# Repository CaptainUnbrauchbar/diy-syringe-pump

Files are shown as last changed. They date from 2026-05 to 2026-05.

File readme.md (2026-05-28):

# DIY Syringe Pump project

This is the code for a DIY syringe pump project. The project targets an Arduino UNO R4 Minima and uses a stepper motor to control the infusion rate of a syringe. The code includes settings for the motor, syringe, and user interface, as well as functions for controlling the motor and displaying information on an LCD screen.

The CAD Files are designed for use with a '50ml BBRAUN Perfusor Syringe' but can easily be adjusted for any other syringe.

Arduino UNO R4 Minima note: the sketch uses `Serial1` on D0/D1 for the TMC2209 UART. For the Adafruit TMC2209 breakout with one `UART` pin, connect that single UART signal to both D1/TX1 and D0/RX1 so the sketch can send commands and read driver status. The backward endstop input moves to D11 on UNO R4.

See [hardware-connection-overview.html](hardware-connection-overview.html) for the full pin assignment and wiring overview.

Parts list incomplete, following soon

Parts list:

| Item | Qty | Description | Link | Notes |
| --- | ---: | --- | --- | --- |
| Arduino UNO R4 Minima | 1 |  |  |  |
| NEMA 17 Stepper motor | 1 |  |  |  |
| TMC2209 Stepper driver | 1 |  |  |  |
| T8 Spindle | 1 | |  |  |
| M8 Linear Rod | 2 |  |  | 
| Coupling Motor <-> T8 Spindle | 1 | | |
| LCD display 16x2, Arduino Uno Header | 1 |  |  |  |
| Power supply (12V, 2A recommended) | 1 |  |  |  |
| Endstop Switch | 2 |  |  |  |
| Buzzer | 1 |  |  |  |

| Bearings | Qty | Description |
| --- | ---: | --- |
| LM8SUU | 2 | Linear bearing 8mm x 15mm x 17mm |
| T8 Flange Bearing | 1 | Flange bearing for T8 spindle |

| Screws | Qty |
| --- | ---: |
| M2 Flathead | 6 |
| M3 Countersunk Head | 16+ |
| M3 Flathead | 4 |
| M5 Flathead | 2 |

CAD Files created with FreeCAD, 3D Printed with PLA

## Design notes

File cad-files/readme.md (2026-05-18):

# Perfusor CAD Files - Created with FreeCAD

Meshes exported in high quality

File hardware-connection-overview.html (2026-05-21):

# DIY Syringe Pump Hardware Connection Overview

This page matches the current diy-syringe-pump.ino sketch for Arduino UNO R4 Minima. It assumes the 2.4/2.8 inch Uno-style parallel TFT shield is installed, and that the motor is driven through an Adafruit TMC2209 breakout with a single half-duplex UART pin.

Target board: UNO R4 Minima Display: Uno parallel TFT shield Driver: Adafruit TMC2209 breakout Current sketch uses UART readback

## Quick Wiring Summary

### UNO R4 Pins In Use

D0TMC2209 UART net (RX1)

D1TMC2209 UART net (TX1)

D2TFT data bit D2

D3TFT data bit D3

D4TFT data bit D4

D5TFT data bit D5

D6TFT data bit D6

D7TFT data bit D7

D8TFT data bit D0, touch XP

D9TFT data bit D1, touch YM

D10TMC2209 STEP

D11Backward endstop

D13Buzzer positive

A0TFT RD

A1TFT WR

A2TFT CD/RS, touch XM

A3TFT CS, touch YP

A4TFT RESET

A5Forward endstop

5VTMC2209 VDD, TFT shield VCC

GNDCommon ground for everything

Direct logic signal Shared with TFT/touch shield Power or ground

### TMC2209 Breakout

- UNO R4 D10 -> TMC2209 STEP
- UNO R4 D1 / TX1 -> TMC2209 UART net
- UNO R4 D0 / RX1 -> same TMC2209 UART net
- UNO R4 5V -> TMC2209 VDD
- UNO R4 GND -> TMC2209 GND
- Motor PSU + -> TMC2209 terminal +
- Motor PSU - -> TMC2209 terminal - / GND
- Stepper coil A -> 1A / 1B
- Stepper coil B -> 2A / 2B

### Endstops and Buzzer

- Forward endstop -> A5
- Backward endstop -> D11
- Buzzer + -> D13
- Buzzer - -> GND

The TFT shield already occupies D2-D9 and A0-A4. Those pins are not free for other hardware.

Important TMC2209 UART note: this sketch does more than send commands; it also verifies readback from the driver. Because the Adafruit breakout has a single UART pin, that pin has to sit on a shared half-duplex UART net that reaches both D1/TX1 and D0/RX1. A one-way TX-only connection is not enough for this sketch.

## What The Sketch Actually Uses

### Used on the TMC2209

- STEP is used directly from D10.
- UART is used for configuration, enable/disable, and motor direction.
- VDD, GND, and motor power are required.
- 1A / 1B / 2A / 2B go to the motor coils.

### Not used by this sketch

- DIR is not wired because direction is sent over UART.
- EN is not wired because enable is sent over UART.
- DIAG and INDEX are not connected.
- MS1 / MS2 are not required because microstepping is configured over UART.

If UART is not working, the sketch will usually stop with a TMC2209 UART error instead of starting the pump.

## Pin Assignment Table

UNO R4 Pin | Connected To | Purpose | Notes
D0 / RX1 | TMC2209 UART | UART readback from driver | Must be on the same single-wire UART net as the breakout UART pin.
D1 / TX1 | TMC2209 UART | UART commands to driver | USB upload/monitor on UNO R4 is still separate from this pin pair.
D10 | TMC2209 STEP | Step pulse output | Still required even though other driver control is done over UART.
D11 | Backward endstop | Retract/home limit input | Moved here because D0 is used for Serial1 on UNO R4.
D13 | Buzzer positive | Alarm/status sound | Connect buzzer negative to GND.
A5 | Forward endstop | Infusion-end limit input | Separate from the TFT shield pins.
D2-D9 | TFT shield data bus | Parallel display interface | The shield expects these exact Uno-style pins.
A0-A4 | TFT shield control pins | RD/WR/CD/CS/RESET | These are also part of the touch-screen sharing arrangement.
D8, D9, A2, A3 | Resistive touch panel | Touch sensing | These are shared with the TFT shield and are already handled by the sketch.
5V | TMC2209 VDD, TFT shield VCC | Logic power | TMC2209 logic should match the UNO R4's 5 V logic supply.
GND | All grounds | Common reference | UNO, TMC2209, motor PSU, buzzer, and endstops must share ground.

## TFT Shield Map

Shield Signal | UNO R4 Pin | Notes
LCD_D0 | D8 | Shared with touch XP
LCD_D1 | D9 | Shared with touch YM
LCD_D2 | D2 | Shield bus
LCD_D3 | D3 | Shield bus
LCD_D4 | D4 | Shield bus
LCD_D5 | D5 | Shield bus
LCD_D6 | D6 | Shield bus
LCD_D7 | D7 | Shield bus
LCD_RD | A0 | Read strobe
LCD_WR | A1 | Write strobe
LCD_CD/RS | A2 | Shared with touch XM
LCD_CS | A3 | Shared with touch YP
LCD_RESET | A4 | Shield reset

If your TFT is a standard Uno shield, you normally do not wire these individually; the shield stacks directly onto the UNO R4 headers.

## Endstop and Power Notes

Endstop logic: the sketch sets both endstop inputs to INPUT_PULLUP and treats a HIGH reading as active. That matches a normally closed (NC) switch wired between the pin and GND, where the pin goes HIGH when the switch opens at the limit.

- If your endstops are normally open (NO), the current logic will not match and you should either rewire them or invert the logic in the sketch.
- The TMC2209 motor power should come from the motor supply, not from the UNO 5V pin.
- Motor coil order is not defined by the sketch. If direction or motion is wrong, swap one coil pair or adjust the motor direction setting in software.
- The sketch configures the TMC2209 for 32 microsteps over UART and expects address 0.

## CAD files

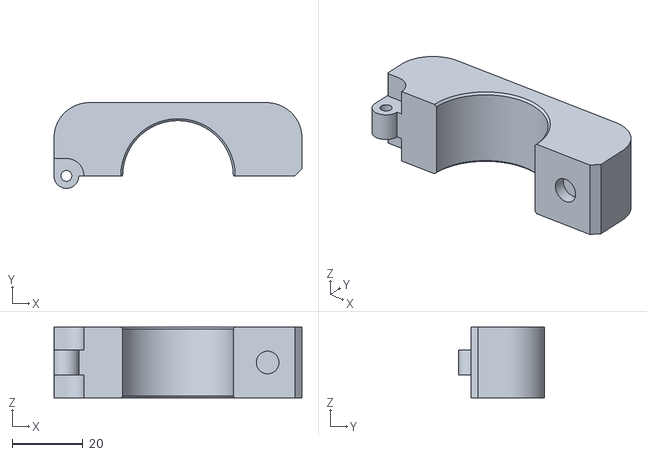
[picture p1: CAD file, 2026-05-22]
cad-files/Syringe-Pump-50ml-Aufsatz_Front_Syringe_Support (Meshed).stl
70.0 x 24.2 x 20.0

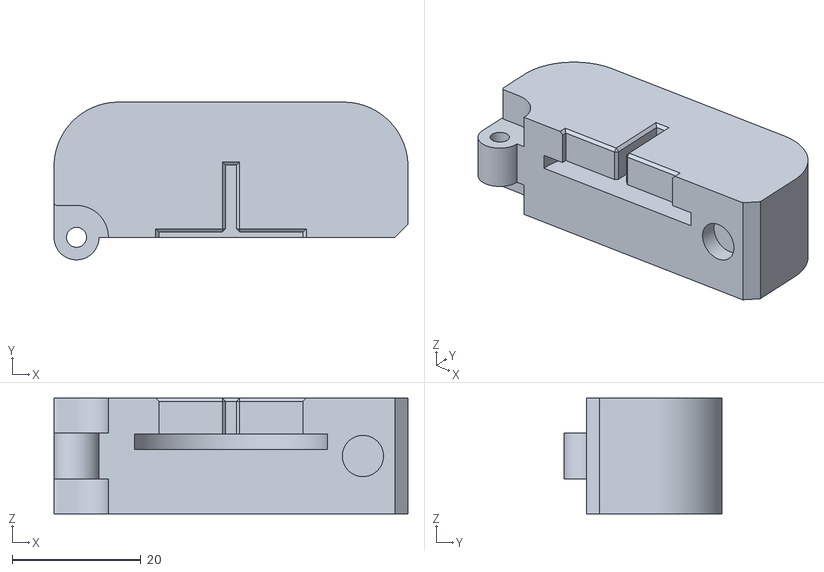
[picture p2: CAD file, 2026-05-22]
cad-files/Syringe-Pump-50ml-Aufsatz_Mid_Carriage (Meshed).stl
55.0 x 24.5 x 18.0

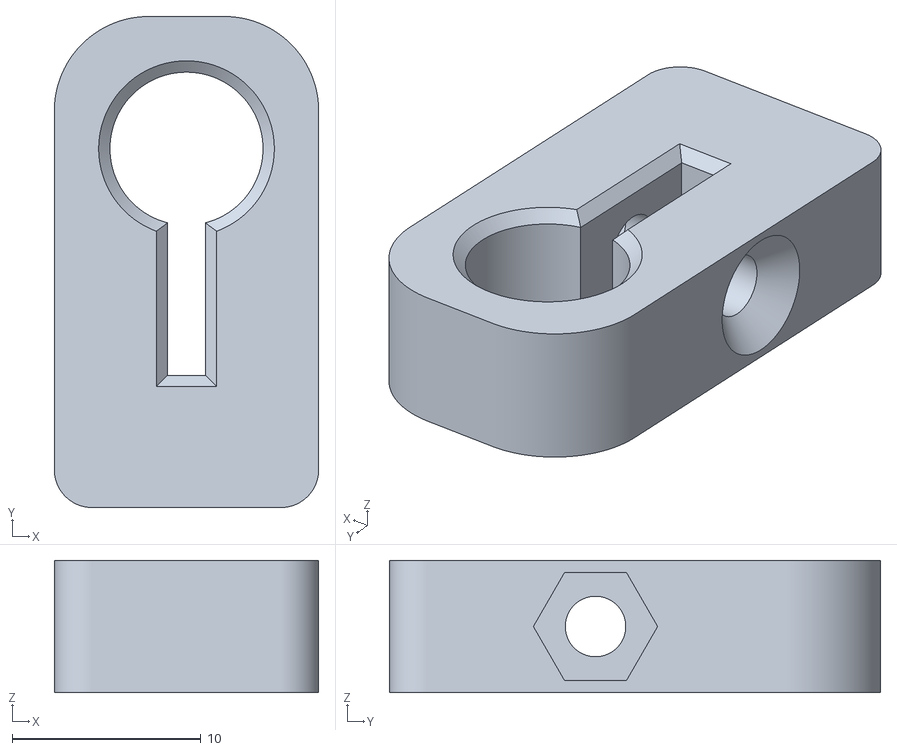
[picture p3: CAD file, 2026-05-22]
cad-files/Syringe-Pump-50ml-Limit_Stop (Meshed).stl
14.0 x 26.0 x 7.00

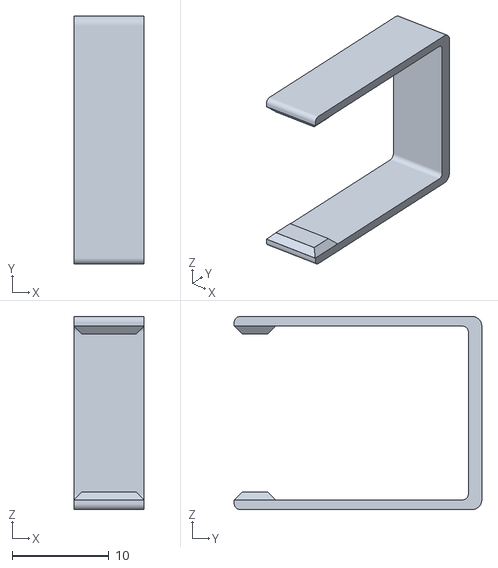
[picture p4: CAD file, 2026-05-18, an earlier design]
cad-files/legacy/Syringe-Pump-50ml-Clamp_Mid_Carriage (Meshed).stl
7.30 x 25.7 x 20.0

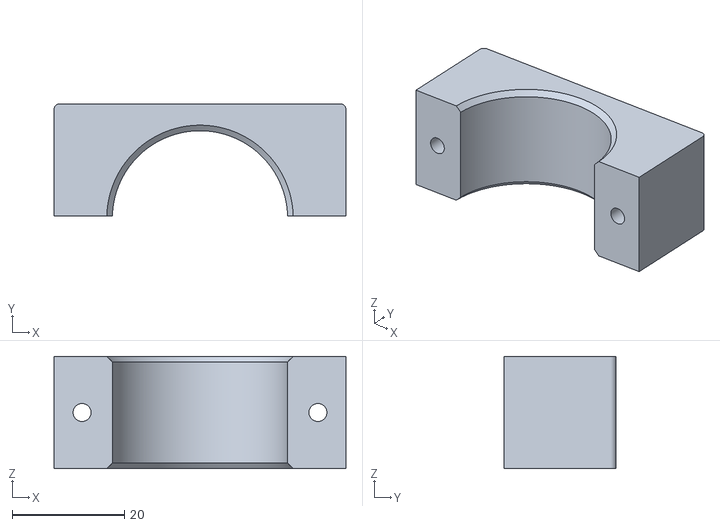
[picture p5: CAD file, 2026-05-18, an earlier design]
cad-files/legacy/Syringe-Pump-50ml-Lock_Front_Syringe_Support (Meshed).stl
52.0 x 20.0 x 20.0

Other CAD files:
cad-files/legacy/Syringe-Pump-50ml-Limit_Stop (Meshed).stl

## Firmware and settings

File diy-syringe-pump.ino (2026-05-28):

#include <Arduino.h>
#include <Adafruit_GFX.h>
#include <EEPROM.h>
#include <TMCStepper.h>
#include <stddef.h>
#include <stdio.h>

#ifndef PROGMEM
#define PROGMEM
#endif
#ifndef PGM_P
#define PGM_P const char *
#endif
#ifndef pgm_read_byte
#define pgm_read_byte(address_short) (*(const uint8_t *)(address_short))
#endif

/********************************************************************
	Basic syringe pump firmware for Arduino UNO R4 Minima
********************************************************************/

// Stepper motor and mechanics
#define NOFMICROSTEPS 64
#define NOFSTEPSPER360 200
#define MAXRPM 180
// Manual syringe-loading jog is loop-limited because STEP pulses are
// generated in software while the touchscreen ADC is being polled. Use a
// separate, much coarser microstep setting here so each emitted step moves
// the carriage farther and the jog feels responsive.
#define STARTUP_JOG_MICROSTEPS 4
#define STARTUP_JOG_MAX_RPM 300
#define INVERTDIRECTION true
#define MMPER360 8.0
#define MOTOR_CURRENT_MA 1200

// Syringe setup
#define DEFAULT_FLOW_ML_PER_HOUR 50.00
#define MIN_FLOW_ML_PER_HOUR 1.00
#define MAX_FLOW_ML_PER_HOUR 600.00
#define FLOW_STEP_ML_PER_HOUR 1.00
#define DEFAULT_FLOW_CENTI_ML_PER_HOUR 5000UL
#define MIN_FLOW_CENTI_ML_PER_HOUR 100UL
#define MAX_FLOW_CENTI_ML_PER_HOUR 60000UL
#define DEFAULT_DELIVERY_ML_PER_CM 3.57
#define MIN_DELIVERY_ML_PER_CM 0.01
#define MAX_DELIVERY_ML_PER_CM 999.99
#define DEFAULT_DELIVERY_CENTI_ML_PER_CM 357UL
#define MIN_DELIVERY_CENTI_ML_PER_CM 1UL
#define MAX_DELIVERY_CENTI_ML_PER_CM 99999UL
#define DEFAULT_SYRINGE_CENTI_ML 5000UL
#define MIN_SYRINGE_CENTI_ML 100UL
#define MAX_SYRINGE_CENTI_ML 10000UL
#define DEFAULT_BOLUS_ML 1.00
#define MIN_BOLUS_CENTI_ML 10UL
#define DEFAULT_BOLUS_ENABLED 1
#define DEFAULT_SOUND_ENABLED 1
#define DEFAULT_MAX_BOLUS_PERCENT 10
#define MIN_MAX_BOLUS_PERCENT 1
#define MAX_MAX_BOLUS_PERCENT 50
#define DEFAULT_STARTUP_JOG_SPEED_PERCENT 50
#define MIN_STARTUP_JOG_SPEED_PERCENT 10
#define MAX_STARTUP_JOG_SPEED_PERCENT 100
#define STARTUP_JOG_SPEED_STEP_PERCENT 10
#define BOLUS_DURATION_MS 10000UL
#define BOLUS_MENU_TIMEOUT_MS 5000UL
#define STATUS_DISPLAY_MS 1200UL
#define MOTOR_TEST_STEP_RATE_HZ 10.0

// Arduino UNO R4 Minima + parallel TFT shield pin plan.
// The TFT shield uses D2-D9 and A0-A4. Its SD-card SPI pins are repurposed.
// TMC2209 UART config replaces the separate DIR and ENABLE pins, but STEP
// pulses are still required; the TMC2209 cannot generate motion from UART only.
#define STEP_PIN 10
// UNO R4 Minima has hardware Serial1 on D0/D1. Move the backward endstop to D11.
#define ENDSTOP_PIN_FORWARD A5
#define ENDSTOP_PIN_BACKWARD 11
#define BUZZER_PIN 13

#define TFT_TOUCH_YP A3
#define TFT_TOUCH_XM A2
#define TFT_TOUCH_YM 9
#define TFT_TOUCH_XP 8

#define TMC2209_UART_BAUD 250000UL
#define TMC2209_UART_DRIVER_ADDRESS 0
#define TMC2209_UART_R_SENSE 0.11f
#define TMC2209_EXPECTED_VERSION 0x21
#define TMC2209_READBACK_ATTEMPTS 3
#define TMC2209_CURRENT_TOLERANCE_MA 100

#define DEBOUNCE_DELAY_MS 50
#define DISPLAY_UPDATE_MS 250
#define STEP_PULSE_US 15
#define TOUCH_MIN_PRESSURE 40
#define TOUCH_MAX_PRESSURE 1023
#define TOUCH_ADC_MAX 1023
#define TOUCH_ANALOG_SAMPLES 4
#define TOUCH_SETTLE_US 150
#define TOUCH_DEBOUNCE_MS DEBOUNCE_DELAY_MS
#define TOUCH_RAW_MARGIN 48
#define TOUCH_STABLE_RAW_DELTA 24
#define TOUCH_STABLE_PRESSURE_DELTA 80
// Bottom action bar. Bigger than before for easier targeting but small enough
// that existing body layouts still fit above it (240 - 64 = 176 px content).
#define TOUCH_BUTTON_BAR_HEIGHT 64
#define ACTION_BAR_HEIGHT TOUCH_BUTTON_BAR_HEIGHT
#define ACTION_HEADER_HEIGHT 28
#define ACTION_TITLE_BACK_WIDTH 56
#define ACTION_PRESS_HOLD_INITIAL_MS 380
#define ACTION_PRESS_HOLD_REPEAT_MS 90
#define MAX_ACTION_SLOTS 5
#define LEFT_EDGE_COMPENSATION_PX 14
#define TOP_EDGE_COMPENSATION_PX 12
#define LEFT_EDGE_COMPENSATION_ZONE_PX 56
#define TOP_EDGE_COMPENSATION_ZONE_PX 44

#define TS_SWAP_XY true
#define TS_RAW_TOP_LEFT_X 142
#define TS_RAW_TOP_LEFT_Y 103
#define TS_RAW_TOP_RIGHT_X 139
#define TS_RAW_TOP_RIGHT_Y 890
#define TS_RAW_BOTTOM_RIGHT_X 843
#define TS_RAW_BOTTOM_RIGHT_Y 897
#define TS_RAW_BOTTOM_LEFT_X 915
#define TS_RAW_BOTTOM_LEFT_Y 83

#define TFT_BLACK 0x0000
#define TFT_WHITE 0xFFFF
#define TFT_RED 0xF800
#define TFT_GREEN 0x07E0
#define TFT_BLUE 0x001F
#define TFT_CYAN 0x07FF
#define TFT_YELLOW 0xFFE0
#define TFT_DARKGREY 0x7BEF
#define TFT_NAVY 0x000F

// Cached fast pin access: on the Renesas UNO R4 core the register and mask
// widths differ from classic AVR boards, so use UNO R4-sized types here.
typedef volatile uint16_t *FastPortReg;
typedef uint16_t FastPortMask;

class UnoParallelTft : public Adafruit_GFX
{
public:
	UnoParallelTft() : Adafruit_GFX(240, 320)
	{
	}

	uint16_t readID()
	{
		return 0x9341;
	}

	void begin(uint16_t displayId = 0x9341)
	{
		(void)displayId;
		pinMode(LCD_RD_PIN, OUTPUT);
		pinMode(LCD_WR_PIN, OUTPUT);
		pinMode(LCD_CD_PIN, OUTPUT);
		pinMode(LCD_CS_PIN, OUTPUT);
		pinMode(LCD_RESET_PIN, OUTPUT);
		for (uint8_t index = 0; index < 8; index++)
			pinMode(dataPin(index), OUTPUT);

		// Cache port output register addresses and bitmasks for every TFT
		// pin so the hot pixel path can use direct register bit twiddling
		// instead of the (slow) Arduino digitalWrite() function.
		cachePin(LCD_RD_PIN, rdPortReg_, rdPortMask_);
		cachePin(LCD_WR_PIN, wrPortReg_, wrPortMask_);
		cachePin(LCD_CD_PIN, cdPortReg_, cdPortMask_);
		cachePin(LCD_CS_PIN, csPortReg_, csPortMask_);
		cachePin(LCD_RESET_PIN, rstPortReg_, rstPortMask_);
		for (uint8_t index = 0; index < 8; index++)
			cachePin(dataPin(index), dataPortReg_[index], dataPortMask_[index]);

		fastHigh(rdPortReg_, rdPortMask_);
		fastHigh(wrPortReg_, wrPortMask_);
		fastHigh(csPortReg_, csPortMask_);
		fastHigh(rstPortReg_, rstPortMask_);
		delay(5);
		fastLow(rstPortReg_, rstPortMask_);
		delay(20);
		fastHigh(rstPortReg_, rstPortMask_);
		delay(150);

		writeCommand(0x01);
		delay(150);
		writeCommand(0x28);
		writeCommandData(0xCF, (const uint8_t[]){0x00, 0xC1, 0x30}, 3);
		writeCommandData(0xED, (const uint8_t[]){0x64, 0x03, 0x12, 0x81}, 4);
		writeCommandData(0xE8, (const uint8_t[]){0x85, 0x00, 0x78}, 3);
		writeCommandData(0xCB, (const uint8_t[]){0x39, 0x2C, 0x00, 0x34, 0x02}, 5);
		writeCommandData(0xF7, (const uint8_t[]){0x20}, 1);
		writeCommandData(0xEA, (const uint8_t[]){0x00, 0x00}, 2);
		writeCommandData(0xC0, (const uint8_t[]){0x23}, 1);
		writeCommandData(0xC1, (const uint8_t[]){0x10}, 1);
		writeCommandData(0xC5, (const uint8_t[]){0x3E, 0x28}, 2);
		writeCommandData(0xC7, (const uint8_t[]){0x86}, 1);
		writeCommandData(0x3A, (const uint8_t[]){0x55}, 1);
		writeCommandData(0xB1, (const uint8_t[]){0x00, 0x18}, 2);
		writeCommandData(0xB6, (const uint8_t[]){0x08, 0x82, 0x27}, 3);
		writeCommandData(0xF2, (const uint8_t[]){0x00}, 1);
		writeCommandData(0x26, (const uint8_t[]){0x01}, 1);
		writeCommandData(0xE0, (const uint8_t[]){0x0F, 0x31, 0x2B, 0x0C, 0x0E, 0x08, 0x4E, 0xF1, 0x37, 0x07, 0x10, 0x03, 0x0E, 0x09, 0x00}, 15);
		writeCommandData(0xE1, (const uint8_t[]){0x00, 0x0E, 0x14, 0x03, 0x11, 0x07, 0x31, 0xC1, 0x48, 0x08, 0x0F, 0x0C, 0x31, 0x36, 0x0F}, 15);
		setRotation(0);
		writeCommand(0x11);
		delay(120);
		writeCommand(0x29);
		delay(20);
	}

	void drawPixel(int16_t x, int16_t y, uint16_t color) override
	{
		if (x < 0 || y < 0 || x >= width() || y >= height())
			return;

		beginWrite();
		setAddressWindow(x, y, x, y);
		writeData16(color);
		endWrite();
	}

	void fillRect(int16_t x, int16_t y, int16_t widthValue, int16_t heightValue, uint16_t color) override
	{
		if (widthValue <= 0 || heightValue <= 0 || x >= width() || y >= height())
			return;
		if (x < 0)
		{
			widthValue += x;
			x = 0;
		}
		if (y < 0)
		{
			heightValue += y;
			y = 0;
		}
		if (x + widthValue > width())
			widthValue = width() - x;
		if (y + heightValue > height())
			heightValue = height() - y;
		if (widthValue <= 0 || heightValue <= 0)
			return;

		beginWrite();
		setAddressWindow(x, y, x + widthValue - 1, y + heightValue - 1);
		// CD is already left HIGH at the end of setAddressWindow() so every
		// subsequent byte is treated as pixel data without re-driving CD.
		uint32_t pixelCount = (uint32_t)widthValue * (uint32_t)heightValue;
		uint8_t hi = (uint8_t)(color >> 8);
		uint8_t lo = (uint8_t)(color & 0xFF);
		if (hi == lo)
		{
			// Solid fill where both color bytes are identical (e.g. BLACK,
			// WHITE, DARKGREY). Drive the data pins once, then just pulse
			// WR twice per pixel - no further data-pin updates required.
			driveDataPins(hi);
			uint32_t pulses = pixelCount << 1;
			while (pulses--)
				pulseWr();
		}
		else
		{
			while (pixelCount--)
			{
				driveDataPins(hi);
				pulseWr();
				driveDataPins(lo);
				pulseWr();
			}
		}
		endWrite();
	}

	void fillScreen(uint16_t color) override
	{
		fillRect(0, 0, width(), height(), color);
	}

	void drawFastHLine(int16_t x, int16_t y, int16_t widthValue, uint16_t color) override
	{
		fillRect(x, y, widthValue, 1, color);
	}

	void drawFastVLine(int16_t x, int16_t y, int16_t heightValue, uint16_t color) override
	{
		fillRect(x, y, 1, heightValue, color);
	}

	void invalidateDataBus()
	{
		dataValueValid_ = false;
	}

	void setRotation(uint8_t rotation) override
	{
		rotation &= 3;
		Adafruit_GFX::setRotation(rotation);
		uint8_t madctl = 0x48;
		switch (rotation)
		{
		case 1:
			madctl = 0x28;
			break;
		case 2:
			madctl = 0x88;
			break;
		case 3:
			madctl = 0xE8;
			break;
		default:
			madctl = 0x48;
			break;
		}
		writeCommandData(0x36, &madctl, 1);
	}

private:
	static const uint8_t LCD_RD_PIN = A0;
	static const uint8_t LCD_WR_PIN = A1;
	static const uint8_t LCD_CD_PIN = A2;
	static const uint8_t LCD_CS_PIN = A3;
	static const uint8_t LCD_RESET_PIN = A4;

	uint8_t dataPin(uint8_t index)
	{
		static const uint8_t pins[] = {8, 9, 2, 3, 4, 5, 6, 7};
		return pins[index];
	}

	static inline void fastHigh(FastPortReg reg, FastPortMask mask)
	{
		*reg |= mask;
	}

	static inline void fastLow(FastPortReg reg, FastPortMask mask)
	{
		*reg &= (FastPortMask)~mask;
	}

	static void cachePin(uint8_t pin, FastPortReg &regOut, FastPortMask &maskOut)
	{
		regOut = (FastPortReg)portOutputRegister(digitalPinToPort(pin));
		maskOut = (FastPortMask)digitalPinToBitMask(pin);
	}

	inline void pulseWr()
	{
		fastLow(wrPortReg_, wrPortMask_);
		fastHigh(wrPortReg_, wrPortMask_);
	}

	inline void driveDataPins(uint8_t value)
	{
		// Only touch data pins whose value actually changes. Most UI fills
		// alternate between two byte values (e.g. 0x00/0x0F for NAVY), so this
		// avoids redundant port writes on every pixel while preserving the
		// generic pin mapping for both AVR Uno and UNO R4.
		uint8_t changed = dataValueValid_ ? (uint8_t)(value ^ lastDataValue_) : 0xFF;
		if (!changed)
			return;
		if (changed & 0x01) { if (value & 0x01) fastHigh(dataPortReg_[0], dataPortMask_[0]); else fastLow(dataPortReg_[0], dataPortMask_[0]); }
		if (changed & 0x02) { if (value & 0x02) fastHigh(dataPortReg_[1], dataPortMask_[1]); else fastLow(dataPortReg_[1], dataPortMask_[1]); }
		if (changed & 0x04) { if (value & 0x04) fastHigh(dataPortReg_[2], dataPortMask_[2]); else fastLow(dataPortReg_[2], dataPortMask_[2]); }
		if (changed & 0x08) { if (value & 0x08) fastHigh(dataPortReg_[3], dataPortMask_[3]); else fastLow(dataPortReg_[3], dataPortMask_[3]); }
		if (changed & 0x10) { if (value & 0x10) fastHigh(dataPortReg_[4], dataPortMask_[4]); else fastLow(dataPortReg_[4], dataPortMask_[4]); }
		if (changed & 0x20) { if (value & 0x20) fastHigh(dataPortReg_[5], dataPortMask_[5]); else fastLow(dataPortReg_[5], dataPortMask_[5]); }
		if (changed & 0x40) { if (value & 0x40) fastHigh(dataPortReg_[6], dataPortMask_[6]); else fastLow(dataPortReg_[6], dataPortMask_[6]); }
		if (changed & 0x80) { if (value & 0x80) fastHigh(dataPortReg_[7], dataPortMask_[7]); else fastLow(dataPortReg_[7], dataPortMask_[7]); }
		lastDataValue_ = value;
		dataValueValid_ = true;
	}

	void beginWrite()
	{
		fastLow(csPortReg_, csPortMask_);
	}

	void endWrite()
	{
		fastHigh(csPortReg_, csPortMask_);
	}

	void writeCommand(uint8_t command)
	{
		beginWrite();
		writeCommandByte(command);
		endWrite();
	}

	void writeCommandData(uint8_t command, const uint8_t *data, uint8_t dataLength)
	{
		beginWrite();
		writeCommandByte(command);
		while (dataLength--)
			writeData8(*data++);
		endWrite();
	}

	void writeCommandByte(uint8_t command)
	{
		fastLow(cdPortReg_, cdPortMask_);
		write8(command);
	}

	void writeData8(uint8_t data)
	{
		fastHigh(cdPortReg_, cdPortMask_);
		write8(data);
	}

	void writeData16(uint16_t data)
	{
		writeData8((uint8_t)(data >> 8));
		writeData8((uint8_t)(data & 0xFF));
	}

	void setAddressWindow(uint16_t x0, uint16_t y0, uint16_t x1, uint16_t y1)
	{
		writeCommandByte(0x2A);
		writeData16(x0);
		writeData16(x1);
		writeCommandByte(0x2B);
		writeData16(y0);
		writeData16(y1);
		writeCommandByte(0x2C);
		fastHigh(cdPortReg_, cdPortMask_);
	}

	void write8(uint8_t value)
	{
		driveDataPins(value);
		pulseWr();
	}

	FastPortReg dataPortReg_[8];
	FastPortMask dataPortMask_[8];
	FastPortReg rdPortReg_;
	FastPortMask rdPortMask_;
	FastPortReg wrPortReg_;
	FastPortMask wrPortMask_;
	FastPortReg cdPortReg_;
	FastPortMask cdPortMask_;
	FastPortReg csPortReg_;
	FastPortMask csPortMask_;
	FastPortReg rstPortReg_;
	FastPortMask rstPortMask_;
	uint8_t lastDataValue_ = 0;
	bool dataValueValid_ = false;
};
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
void loop()
{
	serviceWatchdog();
	serviceMotorClock();
	updateBuzzer();
	Button button = readButtonPress();
	if (currentScreen == SCREEN_STARTUP_SPLASH || currentScreen == SCREEN_STARTUP_INFO)
	{
		updateStartupScreens(button);
		return;
	}

	updateStatusScreen();

	if (alarmActive)
	{
		if (button == BUTTON_SELECT)
			clearAlarm();
		return;
	}

	if (!pumpRunning)
	{
		if (statusActive)
		{
			if (button == BUTTON_SELECT)
				acknowledgeStatus();
			return;
		}

		updateSettingsSupportScreen();
		handleUiButton(button);
		return;
	}

	if (!statusActive)
		handlePumpButton(button);
	else if (button == BUTTON_LEFT)
		stopPump(STOP_MANUAL);

	updateBolusState();

	if (!pumpRunning)
		return;

	if (!timerIsRunning())
	{
		if (endstopInterruptLatched || anyEndstopActive())
			stopPump(STOP_ENDSTOP);
		else
			stopPump(STOP_TIMER_ERROR);
		return;
	}

	// Manual bolus delivery counts toward the target volume. This avoids
	// delivering more than the selected total volume during volume/time runs.
	if (targetVolumeEnabled && pumpedMlFromSteps(atomicStepCounter()) >= targetVolumeMl)
	{
		stopPump(STOP_TARGET_VOLUME);
		return;
	}

	if (millis() - lastDisplayMillis >= DISPLAY_UPDATE_MS)
	{
		if (statusActive)
			lastDisplayMillis = millis();
		else if (currentScreen == SCREEN_EDIT_BOLUS)
			showBolusEditor();
		else if (currentScreen == SCREEN_CONFIRM_BOLUS)
			showBolusConfirm();
		else
			showPumpScreen();
	}
}

RawTouch readTouch()
{
	RawTouch raw = {readTouchAxisX(), readTouchAxisY(), readTouchPressure()};
	if (raw.z >= TOUCH_MIN_PRESSURE && raw.z <= TOUCH_MAX_PRESSURE)
	{
		RawTouch confirm = {readTouchAxisX(), readTouchAxisY(), readTouchPressure()};
		if (abs(raw.x - confirm.x) <= TOUCH_STABLE_RAW_DELTA &&
			abs(raw.y - confirm.y) <= TOUCH_STABLE_RAW_DELTA &&
			abs(raw.z - confirm.z) <= TOUCH_STABLE_PRESSURE_DELTA)
		{
			raw.x = (int16_t)((raw.x + confirm.x) / 2);
			raw.y = (int16_t)((raw.y + confirm.y) / 2);
			raw.z = (int16_t)((raw.z + confirm.z) / 2);
		}
		else
		{
			raw.x = 0;
			raw.y = 0;
			raw.z = 0;
		}
	}
	restoreTouchSharedPins();
	return raw;
}

bool isPressed(const RawTouch &point)
{
	int16_t rawMinX = min(TS_RAW_TOP_LEFT_X, TS_RAW_TOP_RIGHT_X) - TOUCH_RAW_MARGIN;
	int16_t rawMaxX = max(TS_RAW_BOTTOM_LEFT_X, TS_RAW_BOTTOM_RIGHT_X) + TOUCH_RAW_MARGIN;
	int16_t rawMinY = min(TS_RAW_TOP_LEFT_Y, TS_RAW_BOTTOM_LEFT_Y) - TOUCH_RAW_MARGIN;
	int16_t rawMaxY = max(TS_RAW_TOP_RIGHT_Y, TS_RAW_BOTTOM_RIGHT_Y) + TOUCH_RAW_MARGIN;
	return point.z >= TOUCH_MIN_PRESSURE && point.z <= TOUCH_MAX_PRESSURE &&
		point.x >= rawMinX && point.x <= rawMaxX &&
		point.y >= rawMinY && point.y <= rawMaxY;
}

int16_t readTouchAxisX()
{
	pinMode(TFT_TOUCH_YP, INPUT);
	pinMode(TFT_TOUCH_YM, INPUT);
	pinMode(TFT_TOUCH_XP, OUTPUT);
	pinMode(TFT_TOUCH_XM, OUTPUT);
	digitalWrite(TFT_TOUCH_XP, HIGH);
	digitalWrite(TFT_TOUCH_XM, LOW);
	delayMicroseconds(TOUCH_SETTLE_US);
	return TOUCH_ADC_MAX - averageAnalogRead(TFT_TOUCH_YP);
}

int16_t readTouchAxisY()
{
	pinMode(TFT_TOUCH_XP, INPUT);
	pinMode(TFT_TOUCH_XM, INPUT);
	pinMode(TFT_TOUCH_YP, OUTPUT);
	pinMode(TFT_TOUCH_YM, OUTPUT);
	digitalWrite(TFT_TOUCH_YP, HIGH);
	digitalWrite(TFT_TOUCH_YM, LOW);
	delayMicroseconds(TOUCH_SETTLE_US);
	return TOUCH_ADC_MAX - averageAnalogRead(TFT_TOUCH_XM);
}

int16_t readTouchPressure()
{
	pinMode(TFT_TOUCH_XP, OUTPUT);
	pinMode(TFT_TOUCH_YM, OUTPUT);
	pinMode(TFT_TOUCH_XM, INPUT);
	pinMode(TFT_TOUCH_YP, INPUT);
	digitalWrite(TFT_TOUCH_XP, LOW);
	digitalWrite(TFT_TOUCH_YM, HIGH);
	delayMicroseconds(TOUCH_SETTLE_US);
	int16_t z1 = averageAnalogRead(TFT_TOUCH_XM);
	int16_t z2 = averageAnalogRead(TFT_TOUCH_YP);
	int16_t pressure = TOUCH_ADC_MAX - (z2 - z1);
	return constrain(pressure, 0, TOUCH_ADC_MAX);
}

int16_t averageAnalogRead(uint8_t pin)
{
	uint32_t total = 0;
	for (uint8_t sample = 0; sample < TOUCH_ANALOG_SAMPLES; sample++)
	{
		serviceMotorClock();
		total += analogRead(pin);
		serviceMotorClock();
	}
	return (int16_t)(total / TOUCH_ANALOG_SAMPLES);
}

void restoreTouchSharedPins()
{
	pinMode(TFT_TOUCH_XP, OUTPUT);
	pinMode(TFT_TOUCH_YM, OUTPUT);
	pinMode(TFT_TOUCH_XM, OUTPUT);
	pinMode(TFT_TOUCH_YP, OUTPUT);
	digitalWrite(TFT_TOUCH_XP, LOW);
	digitalWrite(TFT_TOUCH_YM, LOW);
	digitalWrite(TFT_TOUCH_XM, HIGH);
	digitalWrite(TFT_TOUCH_YP, HIGH);
	tft.invalidateDataBus();
}

int16_t estimateTouchX(const RawTouch &point)
{
	int16_t rawHorizontal = TS_SWAP_XY ? point.y : point.x;
	long rawLeft = (TS_RAW_TOP_LEFT_Y + TS_RAW_BOTTOM_LEFT_Y) / 2;
	long rawRight = (TS_RAW_TOP_RIGHT_Y + TS_RAW_BOTTOM_RIGHT_Y) / 2;
	long mapped = map(rawHorizontal, rawLeft, rawRight, 0, tftWidth - 1);
	return constrain(mapped, 0, tftWidth - 1);
}

int16_t estimateTouchY(const RawTouch &point)
{
	int16_t rawVertical = TS_SWAP_XY ? point.x : point.y;
	long rawTop = (TS_RAW_TOP_LEFT_X + TS_RAW_TOP_RIGHT_X) / 2;
	long rawBottom = (TS_RAW_BOTTOM_LEFT_X + TS_RAW_BOTTOM_RIGHT_X) / 2;
	long mapped = map(rawVertical, rawTop, rawBottom, 0, tftHeight - 1);
	return constrain(mapped, 0, tftHeight - 1);
}

int16_t applyEdgeCompensation(int16_t value, int16_t zone, int16_t maxOffset, int16_t limit)
{
	if (value >= zone || zone <= 0 || maxOffset <= 0)
		return constrain(value, 0, limit);

	long distanceToZone = zone - value;
	long taperedOffset = (distanceToZone * distanceToZone * maxOffset) / ((long)zone * zone);
	return constrain(value + taperedOffset, 0, limit);
}

int16_t mapTouchX(const RawTouch &point)
{
	int16_t rawHorizontal = TS_SWAP_XY ? point.y : point.x;
	int16_t estimatedY = estimateTouchY(point);
	long rawLeft = map(estimatedY, 0, tftHeight - 1, TS_RAW_TOP_LEFT_Y, TS_RAW_BOTTOM_LEFT_Y);
	long rawRight = map(estimatedY, 0, tftHeight - 1, TS_RAW_TOP_RIGHT_Y, TS_RAW_BOTTOM_RIGHT_Y);
	long mapped = map(rawHorizontal, rawLeft, rawRight, 0, tftWidth - 1);
	return applyEdgeCompensation(mapped, LEFT_EDGE_COMPENSATION_ZONE_PX,
		LEFT_EDGE_COMPENSATION_PX, tftWidth - 1);
}

int16_t mapTouchY(const RawTouch &point)
{
	int16_t rawVertical = TS_SWAP_XY ? point.x : point.y;
	int16_t estimatedX = estimateTouchX(point);
	long rawTop = map(estimatedX, 0, tftWidth - 1, TS_RAW_TOP_LEFT_X, TS_RAW_TOP_RIGHT_X);
	long rawBottom = map(estimatedX, 0, tftWidth - 1, TS_RAW_BOTTOM_LEFT_X, TS_RAW_BOTTOM_RIGHT_X);
	long mapped = map(rawVertical, rawTop, rawBottom, 0, tftHeight - 1);
	return applyEdgeCompensation(mapped, TOP_EDGE_COMPENSATION_ZONE_PX,
		TOP_EDGE_COMPENSATION_PX, tftHeight - 1);
}

Button buttonFromTouch(int16_t x, int16_t y)
{
	// Title-bar BACK zone (only honoured if the current screen advertises a
	// back action).
	if (currentScreenHasBack && y < ACTION_HEADER_HEIGHT && x < ACTION_TITLE_BACK_WIDTH)
		return BUTTON_BACK;

	if (currentActionBar.count == 0)
		return BUTTON_NONE;
	if (y < (int16_t)tftHeight - ACTION_BAR_HEIGHT)
		return BUTTON_NONE;

	uint8_t n = currentActionBar.count;
	int16_t slotW = tftWidth / n;
	int16_t slot = x / slotW;
	if (slot < 0)
		slot = 0;
	if (slot >= (int16_t)n)
		slot = n - 1;
	return (Button)currentActionBar.slots[slot].action;
}

// Maps a touch coordinate to the action-bar slot index, or -1 if not on the
// bar. Used by the touch state machine for visual feedback.
static int8_t slotIndexFromTouch(int16_t x, int16_t y)
{
	if (currentActionBar.count == 0)
		return -1;
	if (y < (int16_t)tftHeight - ACTION_BAR_HEIGHT)
		return -1;
	uint8_t n = currentActionBar.count;
	int16_t slotW = tftWidth / n;
	int16_t slot = x / slotW;
	if (slot < 0)
		slot = 0;
	if (slot >= (int16_t)n)
		slot = n - 1;
	return (int8_t)slot;
}

Button readButton()
{
	RawTouch point = readTouch();
	if (!isPressed(point))
		return BUTTON_NONE;
	return buttonFromTouch(mapTouchX(point), mapTouchY(point));
}
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

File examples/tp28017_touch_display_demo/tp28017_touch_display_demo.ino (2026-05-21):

/*
  TP28017 resistive touch display demo for Arduino Uno.

  Required libraries from the Arduino Library Manager:
  - Adafruit GFX Library
  - MCUFRIEND_kbv
  - TouchScreen

  The sketch checks the TFT controller ID, fills the display with test colors,
  draws text and shapes, then shows raw and mapped touch coordinates.
*/

#include <Adafruit_GFX.h>
#include <MCUFRIEND_kbv.h>
#include <TouchScreen.h>

// Common wiring for 2.4/2.8 inch Arduino Uno resistive TFT shields.
// Change these if your TP28017 module documents different touch pins.
#define YP A3
#define XM A2
#define YM 9
#define XP 8

#define SERIAL_BAUD 115200
#define MINPRESSURE 5
#define MAXPRESSURE 1000
#define TOUCH_POLL_DELAY_MS 5
#define SERIAL_LOG_INTERVAL_MS 60
#define LEFT_EDGE_COMPENSATION_PX 14
#define TOP_EDGE_COMPENSATION_PX 12
#define LEFT_EDGE_COMPENSATION_ZONE_PX 56
#define TOP_EDGE_COMPENSATION_ZONE_PX 44

// Fixed calibration captured from measured corner touches.
#define TS_SWAP_XY true
#define TS_RAW_TOP_LEFT_X 142
#define TS_RAW_TOP_LEFT_Y 103
#define TS_RAW_TOP_RIGHT_X 139
#define TS_RAW_TOP_RIGHT_Y 890
#define TS_RAW_BOTTOM_RIGHT_X 843
#define TS_RAW_BOTTOM_RIGHT_Y 897
#define TS_RAW_BOTTOM_LEFT_X 915
#define TS_RAW_BOTTOM_LEFT_Y 83

#define BLACK 0x0000
#define WHITE 0xFFFF
#define RED 0xF800
#define GREEN 0x07E0
#define BLUE 0x001F
#define CYAN 0x07FF
#define MAGENTA 0xF81F
#define YELLOW 0xFFE0

MCUFRIEND_kbv tft;
TouchScreen touch = TouchScreen(XP, YP, XM, YM, 300);

uint16_t screenWidth;
uint16_t screenHeight;
unsigned long lastTouchLogAtMs = 0;

struct RawTouch
{
  int16_t x;
  int16_t y;
  int16_t z;
};

RawTouch readTouch();
bool isPressed(const RawTouch &point);
int16_t estimateTouchX(const RawTouch &point);
int16_t estimateTouchY(const RawTouch &point);
int16_t applyEdgeCompensation(int16_t value, int16_t zone, int16_t maxOffset, int16_t limit);
int16_t mapTouchX(const RawTouch &point);
int16_t mapTouchY(const RawTouch &point);

void showCenteredText(const char *text, int16_t y, uint8_t size, uint16_t color)
{
  int16_t x1;
  int16_t y1;
  uint16_t textWidth;
  uint16_t textHeight;

  tft.setTextSize(size);
  tft.getTextBounds(text, 0, y, &x1, &y1, &textWidth, &textHeight);
  tft.setCursor((screenWidth - textWidth) / 2, y);
  tft.setTextColor(color);
  tft.print(text);
}

void runColorTest()
{
  const uint16_t colors[] = {RED, GREEN, BLUE, CYAN, MAGENTA, YELLOW, WHITE, BLACK};

  for (uint8_t index = 0; index < sizeof(colors) / sizeof(colors[0]); index++) {
    tft.fillScreen(colors[index]);
    delay(350);
  }
}

RawTouch readTouch()
{
  TSPoint point = touch.getPoint();

  pinMode(XM, OUTPUT);
  pinMode(YP, OUTPUT);

  RawTouch raw = {point.x, point.y, point.z};
  return raw;
}

bool isPressed(const RawTouch &point)
{
  return point.z >= MINPRESSURE && point.z <= MAXPRESSURE;
}

int16_t estimateTouchX(const RawTouch &point)
{
  int16_t rawHorizontal = TS_SWAP_XY ? point.y : point.x;
  long rawLeft = (TS_RAW_TOP_LEFT_Y + TS_RAW_BOTTOM_LEFT_Y) / 2;
  long rawRight = (TS_RAW_TOP_RIGHT_Y + TS_RAW_BOTTOM_RIGHT_Y) / 2;
  long mapped = map(rawHorizontal, rawLeft, rawRight, 0, screenWidth - 1);
  return constrain(mapped, 0, screenWidth - 1);
}

int16_t estimateTouchY(const RawTouch &point)
{
  int16_t rawVertical = TS_SWAP_XY ? point.x : point.y;
  long rawTop = (TS_RAW_TOP_LEFT_X + TS_RAW_TOP_RIGHT_X) / 2;
  long rawBottom = (TS_RAW_BOTTOM_LEFT_X + TS_RAW_BOTTOM_RIGHT_X) / 2;
  long mapped = map(rawVertical, rawTop, rawBottom, 0, screenHeight - 1);
  return constrain(mapped, 0, screenHeight - 1);
}

int16_t applyEdgeCompensation(int16_t value, int16_t zone, int16_t maxOffset, int16_t limit)
{
  if (value >= zone || zone <= 0 || maxOffset <= 0) {
    return constrain(value, 0, limit);
  }

  long distanceToZone = zone - value;
  long taperedOffset = (distanceToZone * distanceToZone * maxOffset) / ((long)zone * zone);
  return constrain(value + taperedOffset, 0, limit);
}

int16_t mapTouchX(const RawTouch &point)
{
  int16_t rawHorizontal = TS_SWAP_XY ? point.y : point.x;
  int16_t estimatedY = estimateTouchY(point);
  long rawLeft = map(estimatedY, 0, screenHeight - 1,
                     TS_RAW_TOP_LEFT_Y, TS_RAW_BOTTOM_LEFT_Y);
  long rawRight = map(estimatedY, 0, screenHeight - 1,
                      TS_RAW_TOP_RIGHT_Y, TS_RAW_BOTTOM_RIGHT_Y);
  long mapped = map(rawHorizontal, rawLeft, rawRight, 0, screenWidth - 1);
  return applyEdgeCompensation(mapped, LEFT_EDGE_COMPENSATION_ZONE_PX,
                               LEFT_EDGE_COMPENSATION_PX, screenWidth - 1);
}

int16_t mapTouchY(const RawTouch &point)
{
  int16_t rawVertical = TS_SWAP_XY ? point.x : point.y;
  int16_t estimatedX = estimateTouchX(point);
  long rawTop = map(estimatedX, 0, screenWidth - 1,
                    TS_RAW_TOP_LEFT_X, TS_RAW_TOP_RIGHT_X);
  long rawBottom = map(estimatedX, 0, screenWidth - 1,
                       TS_RAW_BOTTOM_LEFT_X, TS_RAW_BOTTOM_RIGHT_X);
  long mapped = map(rawVertical, rawTop, rawBottom, 0, screenHeight - 1);
  return applyEdgeCompensation(mapped, TOP_EDGE_COMPENSATION_ZONE_PX,
                               TOP_EDGE_COMPENSATION_PX, screenHeight - 1);
}

void drawTestPattern(uint16_t displayId)
{
  tft.fillScreen(BLACK);
  tft.drawRect(0, 0, screenWidth, screenHeight, WHITE);
  tft.drawLine(0, 0, screenWidth - 1, screenHeight - 1, RED);
  tft.drawLine(screenWidth - 1, 0, 0, screenHeight - 1, GREEN);
  tft.fillCircle(screenWidth / 2, screenHeight / 2, 28, BLUE);
  tft.drawCircle(screenWidth / 2, screenHeight / 2, 42, YELLOW);

  showCenteredText("TP28017 TFT Demo", 12, 2, WHITE);

  tft.setTextSize(1);
  tft.setTextColor(CYAN);
  tft.setCursor(8, 40);
  tft.print("LCD ID: 0x");
  tft.print(displayId, HEX);
  tft.setCursor(8, 54);
  tft.print("Touch screen to draw");
  tft.setCursor(8, 68);
  tft.print("Serial Monitor: raw values");
}

void setup()
{
  Serial.begin(SERIAL_BAUD);
  Serial.println(F("TP28017 resistive touch display demo"));

  uint16_t displayId = tft.readID();
  if (displayId == 0xD3D3 || displayId == 0xFFFF || displayId == 0x0000) {
    Serial.println(F("Unknown display ID; using common ILI9341 fallback 0x9341"));
    displayId = 0x9341;
  }

  tft.begin(displayId);
  tft.setRotation(1);
  screenWidth = tft.width();
  screenHeight = tft.height();

  runColorTest();
  drawTestPattern(displayId);
}
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

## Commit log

2026-05-18 Update README with CAD files and parts list information
    Added note about CAD files compatibility and parts list status.
2026-05-19 cad rework
    [Syringe-Pump-50mlFCStd.FCStd]
2026-05-21 cad update
2026-05-28 fw stallguard
